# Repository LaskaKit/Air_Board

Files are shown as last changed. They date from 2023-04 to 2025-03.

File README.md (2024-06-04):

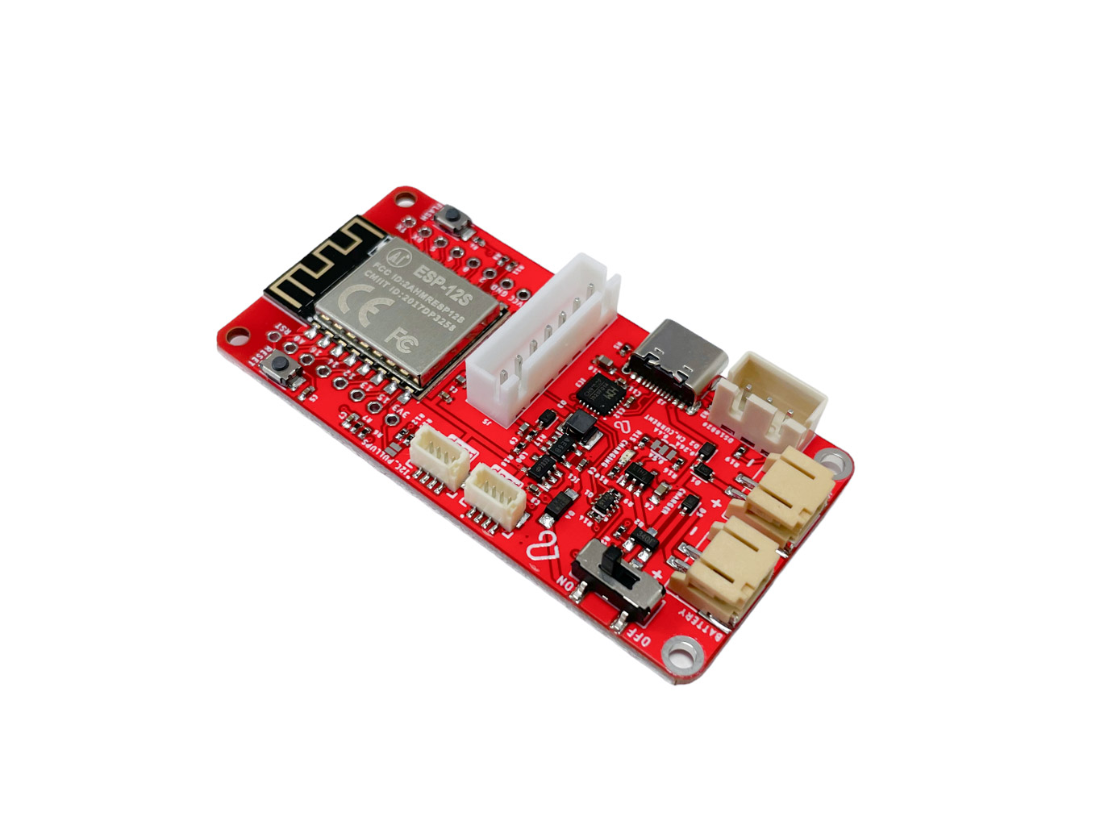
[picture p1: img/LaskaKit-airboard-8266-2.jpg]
Airboard - TOP


# LaskaKit AirBoard ESP8266 

The quality of the air we breathe is very important but unfortunately neglected. Thanks to a close cooperation with [sensorvzduchu.cz](https://www.senzorvzduchu.cz/) we have developed a board fully compatible with https://sensor.community/. This is one of the largest services for storing and visualizing data from home and semi-professional metestanice. 

Of course, it is not necessary to use Airboard only with sensor.community. You can use it with another popular service [TMEP.eu](https://tmep.eu/). Or you can send the data to your own server, where you can run HomeAssistant or Grafana. 

We have fully respected the demands and requirements of the sensor.community during development so that the LaskaKit AirBoard is fully compatible. No obstacles, just improvements over the normal NodeMCU wiring. </br>
And the result? The basis is a fully supported module with ESP8266. To this you can easily connect I2C sensors (SDA - GPIO0, SCL - GPIO2) via two [uSup connectors(what is it?)](https://blog.laskakit.cz/predstavujeme-univerzalni-konektor-pro-propojeni-modulu-a-cidel-%ce%bcsup/). With this connector compatible with SparkFun Qwiic and Adafruit STEMMA, you can connect dozens of different I2C sensors. </br>
Which on? For example [BME688 - Pressure, Temperature, Humidity and Air Quality Sensor](https://www.laskakit.cz/laskakit-bme688-senzor-tlaku--teploty--vlhkosti-a-kvalitu-vzduchu/), [SGP41 - VOC and Nox Air Quality Sensor](https://www.laskakit.cz/laskakit-sgp41-voc-a-nox-senzor-kvality-ovzdusi/) and you can display all that data on the [1.3" OLED display](https://www.laskakit.cz/laskakit-oled-displej-128x64-1-3--i2c/?variantId=11903), [SCD41 for measurement of CO2, temperature and humidity](https://www.laskakit.cz/laskakit-scd41-senzor-co2--teploty-a-vlhkosti-vzduchu/), sensor SHT41 [temperature and humidity](https://www.laskakit.cz/laskakit-sht40-senzor-teploty-a-vlhkosti-vzduchu/) and [sensor of pressure, temperature, humidity BME280](https://www.laskakit.cz/arduino-senzor-tlaku--teploty-a-vlhkosti-bme280/), [RTC - Real Time Clock](https://www.laskakit.cz/laskakit-ds3231-orig--rtc-hodiny-realneho-casu/) with DS323.

The UART is connected to RX (GPIO5), TX (GPIO4) pins, the ADC input from the voltage divider connected to the battery is connected to the single ADC input of the ESP8266.
And that's certainly not all.

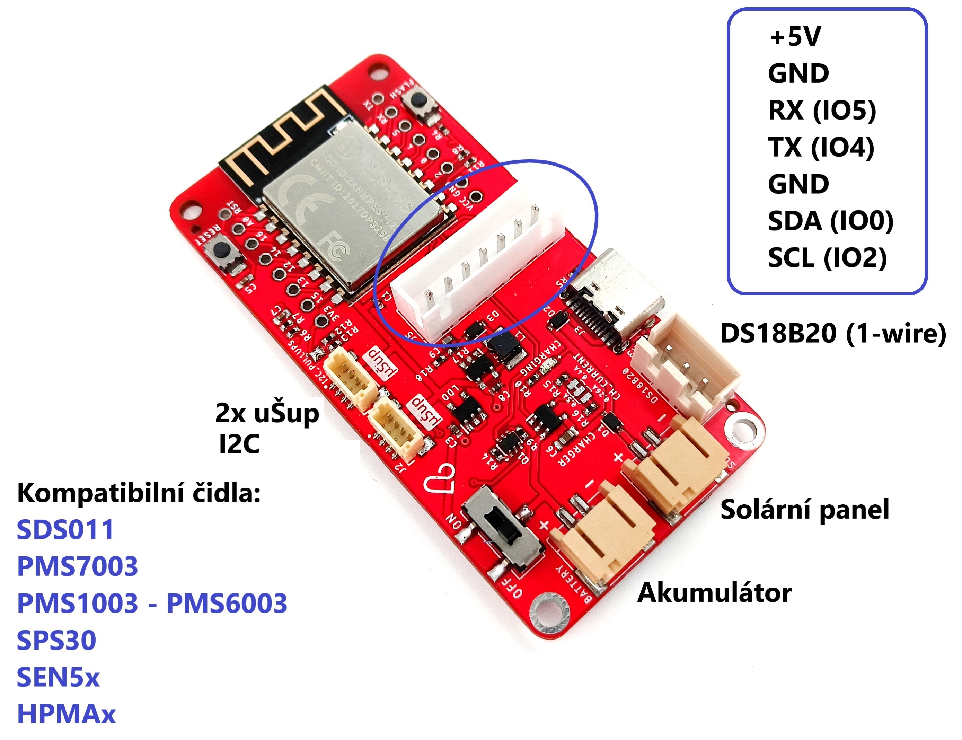
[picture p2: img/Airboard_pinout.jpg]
Airboard - pinout


You can also connect particulate sensors to the AirBoard very easily - there is a 7-pin connector on the board with I2C interface and UART interface and of course power supply. </br>
How and what to connect where we wrote in https://github.com/LaskaKit/Air_Board/blob/main/input/sensors.xlsx</br>
Some sensors need a 5V power supply, usually because of the fan or laser. We also kept this in mind during the design - we added a step-up converter to the board. With this you can power sensors that also need 5V power.

Fro version 1.2, it is now possible to choose whether the 5V output voltage for the connected sensors will be permanently on, or whether it can be switched on/off as needed using GPIO pin IO12.

If you're asking if you can connect a 5V powered sensor to the ESP8266, overwhelmingly yes. The sensors are indeed 5V powered, but the output is 3.3V compatible (but always confirm this in the sensor datasheet).

And what else can you find on the board? Three-pin connector for high-quality connection of temperature sensor DS18B20 (1-wire bus, contains 4k7 pull-up), connector for solar panel (we recommend 6V) and connector for connecting the accumulator.

You don't need a programmer. It is built-in on the board itself. Just plug in the USB-C cable to your laptop and upload your code. 

## This board is available on https://www.laskakit.cz/laskakit-airboard-8266-deska-pro-mereni-kvality-vzduchu/

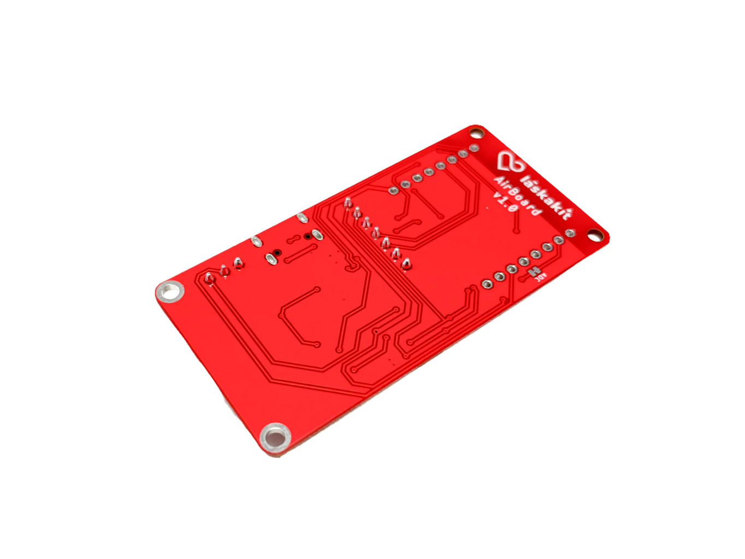
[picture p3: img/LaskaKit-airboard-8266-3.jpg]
Airboard - TOP


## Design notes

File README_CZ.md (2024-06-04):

Airboard - TOP

# LaskaKit AirBoard ESP8266 
Kvalita vzduchu, který dýcháme, je velmi důležitá ale bohužel opomíjená. Díky úzké spolupráci se [senzorvzduchu.cz](https://www.senzorvzduchu.cz/) jsme společně vyvinuli desku plně kompatibilní se https://sensor.community/cz/. To je jedna z největších služeb pro ukládání a vizualizaci dat z domácích a poloprofesionálních metestanice. 

Airboard samozřejmě nemusíš použít jenom se sensor.community. Můžeš jej využít s další populární službou [TMEP.cz](https://tmep.cz/). Nebo si můžeš posílat data na svůj server, kde ti třeba běží HomeAssistant nebo Grafana. 

Plně jsme při vývoji respektovali nároky a požadavky sensor.community tak, aby deska LaskaKit AirBoard byla plně kompatibilní. Žádné překážky, jenom vylepšení oproti běžnému zapojení s NodeMCU. </br>
A výsledek? Základem je plně podporovaný modul s ESP8266. K tomu lze snadno připojit I2C čidla (SDA - GPIO0, SCL - GPIO2) přes dva [uŠup konektory(co to je?)](https://blog.laskakit.cz/predstavujeme-univerzalni-konektor-pro-propojeni-modulu-a-cidel-%ce%bcsup/). Díky tomuto konektoru kompatibilním se SparkFun Qwiic a Adafruit STEMMA, můžeš připojit desítky nejrůznějších I2C čidel. 
UART je připojen na piny RX (GPIO5), TX (GPIO4), ADC vstup z děliče napětí připojeného na akumulátor je připojen na jediný ADC vstup ESP8266.
A to rozhodně není všechno.

Airboard - pinout

K AirBoard můžeš velmi jednoduše připojit i čidla pevných částic - na desce je 7pinový konektor s I2C rozhraním i UART rozhraním a samozřejmě napájením. Díky tomuto konektoru můžeš připojit nejméně 6 typů senzorů pevných částic. Některé moduly navíc obsahují i čidlo teploty a vlhkosti, například SEN5x.</br>
Jak a co kam připojit jsme sepsali v https://github.com/LaskaKit/Air_Board/blob/main/input/sensors.xlsx</br>
Některá čidla potřebují 5V napájení, většinou kvůli ventilátoru nebo laseru. I na toto jsme při návrhu mysleli - na desku jsme přidali step-up (zvyšující) měnič na 5V. Tím můžeš napájet čidla, která potřebují i 5V napájení.

Od verze 1.2 je nově možnost zvolit zda bude výstupní napětí 5V pro připojená čidla trvale zapnuté, nebo ho lze podle potřeby zapínat/vypínat pomocí GPIO pinu IO12.

Pokud se ptáš, jestli můžeš 5V napájené čidlo připojit k ESP8266, tak v drtivé většině ano. Čidla jsou totiž sice napájená 5V, ale výstup je 3.3V kompatibilní (tohle si ale raději vždy potvrď v katalogovém listu čidla).

A co na desce ještě najdeš? Třípinový konektor pro kvalitní připojení čidla teploty DS18B20 (1-wire sběrnice, obsahuje 4k7 pull-up), konektor pro solární panel (ten doporučujeme 6V) a konektor pro připojení akumulátoru. </br>
Ten je napájený z čipu TP4054 a na desce najdeš pájecí most, kterým si zvolíš nabíjecí proud - 260mA nebo 400mA.

K programování budeš nepotřebuješ programátor. Ten už je na desce a stačí tak jenom zapojit USB-C kabel do tvého počítače a nahrát program. 

## Tuto desku si můžeš objednat na https://www.laskakit.cz/laskakit-airboard-8266-deska-pro-mereni-kvality-vzduchu/

Airboard - TOP

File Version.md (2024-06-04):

### Version 1.2
- Přepojení ADC děliče přímo na VBAT
- Přidána propojka ADC dělič <-> VBAT - ADC_BATT
- Přidána možnost spínání pro 5V měnič - IO12
- Změna rezistoru pro LED na 2k
#### Version 1.1
- Added CH9102
#### Version 1.0
- Opraven dělič napětí - 1M/294k
- Změna napájení 5V měniče - napájen přímo z vypínače, ne z 3,3V větve
#### Version 0.0
- Vývojová

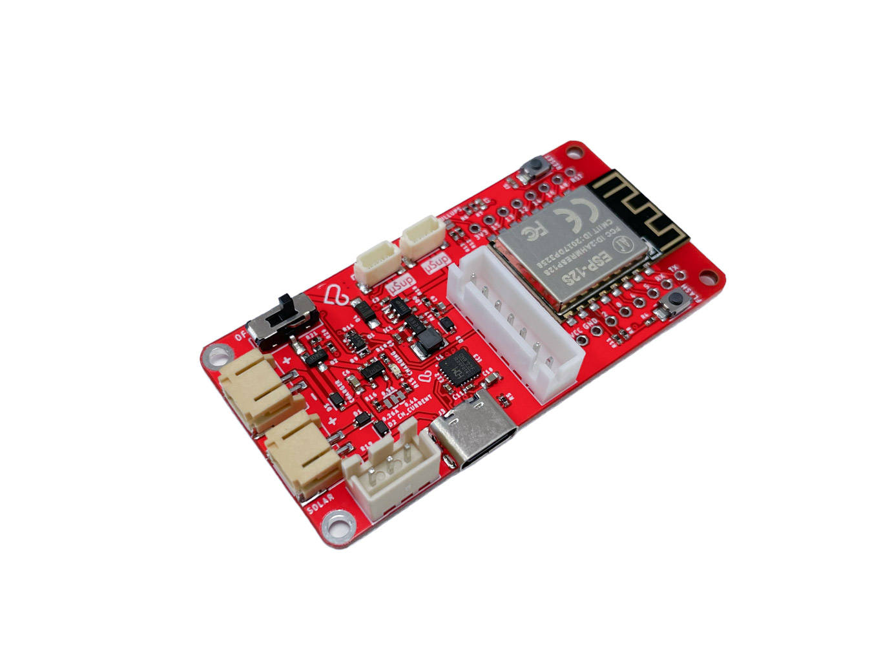
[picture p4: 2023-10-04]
img/LaskaKit-airboard-8266-1.jpg

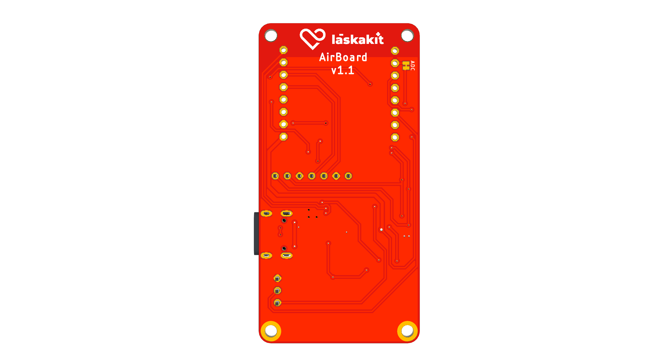
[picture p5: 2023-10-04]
img/LaskaKit_AirBoard_back.png

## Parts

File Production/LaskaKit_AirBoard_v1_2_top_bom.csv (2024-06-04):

Comment | Designator | Footprint | LCSC Part #
1M | R6 R23 | R0402
1N4007W | D4 | SOD123-F
1N5819WS | D3 | SOD323-R
1k65 | R15 | R0402
1uF | C6 | C0603
750 | R10 | R0402
3k3 | R16 | R0402
4.7k | R19 | R0402
5.1k | R18 | R0402
5k1 | R3 R5 | R0402
10k | R1 R2 R4 R8 R9 R11 R12 R13 R14 R20 R22 | R0402
10uH | L1 | L1210 | C86069
15.4k | R17 | R0402
22uF | C2 C3 C4 C8 C9 | C0402
22uF | C10 | C0603
22uF | C13 | C0402
100k | R21 | R0402
100n | C11 C12 | C0402
100nF | C1 C5 C7 | C0402
294k | R7 | R0402
AO3401 | Q2 | SOT23
AP2191WG-7 | IC2 | SOT25 | C141321
AP3012 | IC1 | SOT95P280X135-5N | C460356
BAT60B | D1 D2 D5 | SOD323-R
CH9102F | IC3 | QFN24-4X4
ESP-12 | U1 | ESP12-SMD
HT7833 | LDO | SOT23-5
JST-PH-2/90SMD | BATTERY SOLAR | S2B-PH-SM4 | C47647
JST-SH 4P | J1 J2 | 1X04_1MM_RA_VERT | C371588
MMDT3904 | Q1 | SC70-6 | C268586
RED | CHARGING | CHIP-LED0603 | C241893
TA-3531-A2 | SW1 | TA-3530A-A2 | C514025
TP4054 | CHARGER | SOT-23-5
TS-1088R-02026 | FLASH RESET | TS1088R02026
USB-C_2-16PIN | J3 | USBC_USB-C-16P-5 | C2837092
JST-XH_7P | J5 | JST-XH_7P | C144398
JST-XH_3P | DS18B20 | JST-XH_3P

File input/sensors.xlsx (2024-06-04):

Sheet: Sheet1
 | AirBoard pins and colors | LA131056 SDS011 4.7-5.3V 70mA±10mA
connector | JST-XH-7 | JST-XH-7
1 | 5V | Pin 1 (TX @3.3V) -> (RX) Pin D1 (GPIO5)
2 | GND | Pin 2 (RX@3.3V) -> (TX) Pin D2 (GPIO4)
3 | (RX) Pin D1 (GPIO5) | Pin 3 (GND) -> GND
4 | (TX) Pin D2 (GPIO4) | ~~Pin 4 (2.5m) -> unused~~
5 | GND (SEL) | Pin 5 (5V) -> VU
6 | SDA Pin D3 (GPIO0) | ~~Pin 6 (1m) -> unused~~
7 | SCL Pin D4 (GPIO2) | ~~Pin 7 (NC) -> unused~~
 | AirBoard pins and colors | Honeywell PM sensor 5 V ±0.2 V 80mA max.
connector | JST-XH-7
1 | 5V | ~~Pin 1 (3.3V 100 mA out) -> unused~~
2 | GND | Pin 2 (5V) -> VU
3 | (RX) Pin D1 (GPIO5) | ~~Pin 3 (NC) -> unused~~
4 | (TX) Pin D2 (GPIO4) | ~~Pin 4 (NC) -> unused~~
5 | GND (SEL) | ~~Pin 5 TEST reserved for future use) -> unused~~
6 | SDA Pin D3 (GPIO0) | Pin 6 (TX @3.3V) -> Pin D1 (GPIO5)
7 | SCL Pin D4 (GPIO2) | Pin 7 (RX @3.3V) -> Pin D2 (GPIO4)
 |  | Pin 8 (GND) -> GND
 | AirBoard pins and colors | PMS7003 4.5-5.5V 100mA max.
connector | JST-XH-7
1 | 5V | Pin 1 (5V VCC) -> VU
2 | GND | Pin 2 (5V VCC) -> VU
3 | (RX) Pin D1 (GPIO5) | Pin 3 (GND) -> GND
4 | (TX) Pin D2 (GPIO4) | Pin 4 (GND) -> GND
5 | GND (SEL) | ~~Pin 5 (RESET) -> unused~~
6 | SDA Pin D3 (GPIO0) | ~~Pin 6 (NC) -> unused~~
7 | SCL Pin D4 (GPIO2) | Pin 7 (RX @3.3V) -> Pin D2 (GPIO4)
 |  | ~~Pin 8 (NC) -> unused~~
 |  | Pin 9 (TX @3.3V) -> Pin D1 (GPIO5)
 |  | ~~Pin 10 (SET ) -> unused~~
 | AirBoard pins and colors | PMS1003 to PMS6003 4.5-5.5V
connector | JST-XH-7
1 | 5V | Pin 1 (5V VCC) -> VU
2 | GND | Pin 2 (GND) -> GND
3 | (RX) Pin D1 (GPIO5) | ~~Pin 3 (SET) -> unused~~
4 | (TX) Pin D2 (GPIO4) | Pin 4 (RX @3.3V) -> Pin D2 (GPIO4)
5 | GND (SEL) | Pin 5 (TX @3.3V) -> Pin D1 (GPIO5)
6 | SDA Pin D3 (GPIO0) | ~~Pin 6 (RESET) -> unused~~
7 | SCL Pin D4 (GPIO2) | ~~Pin 7 (NC) -> unused~~
 |  | ~~Pin 8 (NC) -> unused~~
 | AirBoard pins and colors | LA131057 SPS30 (I2C, 4.5 - 5.5V) 80mA max.
connector | JST-XH-7 | JST-ZHR-5
1 | 5V | Pin 1 (5V) -> Pin VU/VIN
2 | GND | Pin 2 (SDA @3.3V) -> Pin D3 (GPIO0)
3 | (RX) Pin D1 (GPIO5) | Pin 3 (SCL @3.3V) -> Pin D4 (GPIO2)
4 | (TX) Pin D2 (GPIO4) | Pin 4 (SEL) -> Pin GND
5 | GND (SEL) | Pin 5 (GND) -> Pin GND
6 | SDA Pin D3 (GPIO0)
7 | SCL Pin D4 (GPIO2)
 | AirBoard pins and colors | LA131058 a LA131059 SEN5x (I2C, 4.5 - 5.5V) 100mA max.
connector | JST-XH-7 | JST-GHT-06V-S
1 | 5V | Pin 1 (5V) -> Pin VU/VIN
2 | GND | Pin 2 (GND) -> Pin GND
3 | (RX) Pin D1 (GPIO5) | Pin 3 (SDA @3.3V) -> Pin D3 (GPIO0)
4 | (TX) Pin D2 (GPIO4) | Pin 4 (SCL @3.3V) -> Pin D4 (GPIO2)
5 | GND (SEL) | Pin 5 (SEL) -> Pin GND
6 | SDA Pin D3 (GPIO0) | ~~Pin 6 (NC) -> unused~~
7 | SCL Pin D4 (GPIO2)

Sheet: SDS011
datasheet (https://www.laskakit.cz/user/related_files/sds011_laser_pm2-5-v1-3.pdf) |  | 5V 70mA±10mA
No | Name | Comment
1 | NC | Not Connect
2 | 1μm | PM2.5: 0-999μg/m3;PWM Output
3 | 5V | 5V Input
4 | 2.5μm | PM10: 0-999 μg/m3;PWM Output
5 | GND | Ground
6 | R | RX of UART(TTL)@3.3V
7 | T | TX of UART(TTL)@3.3V

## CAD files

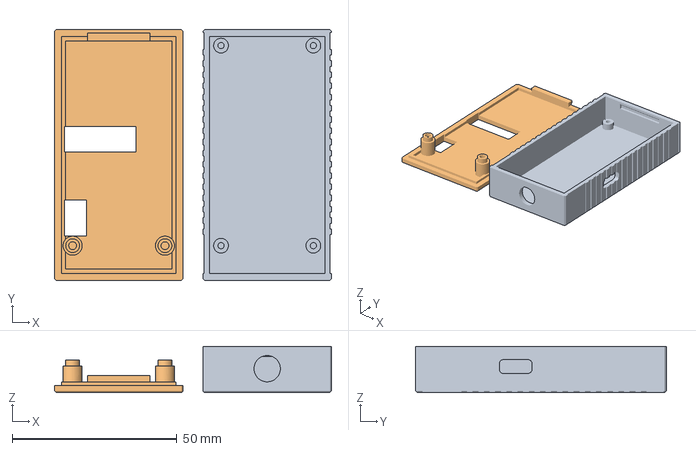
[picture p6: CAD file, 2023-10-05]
3D/airboard_case.3mf
84.0 x 76.0 x 14.0 mm
Top_cover v10.stl
Bottom_cover_general v35.stl

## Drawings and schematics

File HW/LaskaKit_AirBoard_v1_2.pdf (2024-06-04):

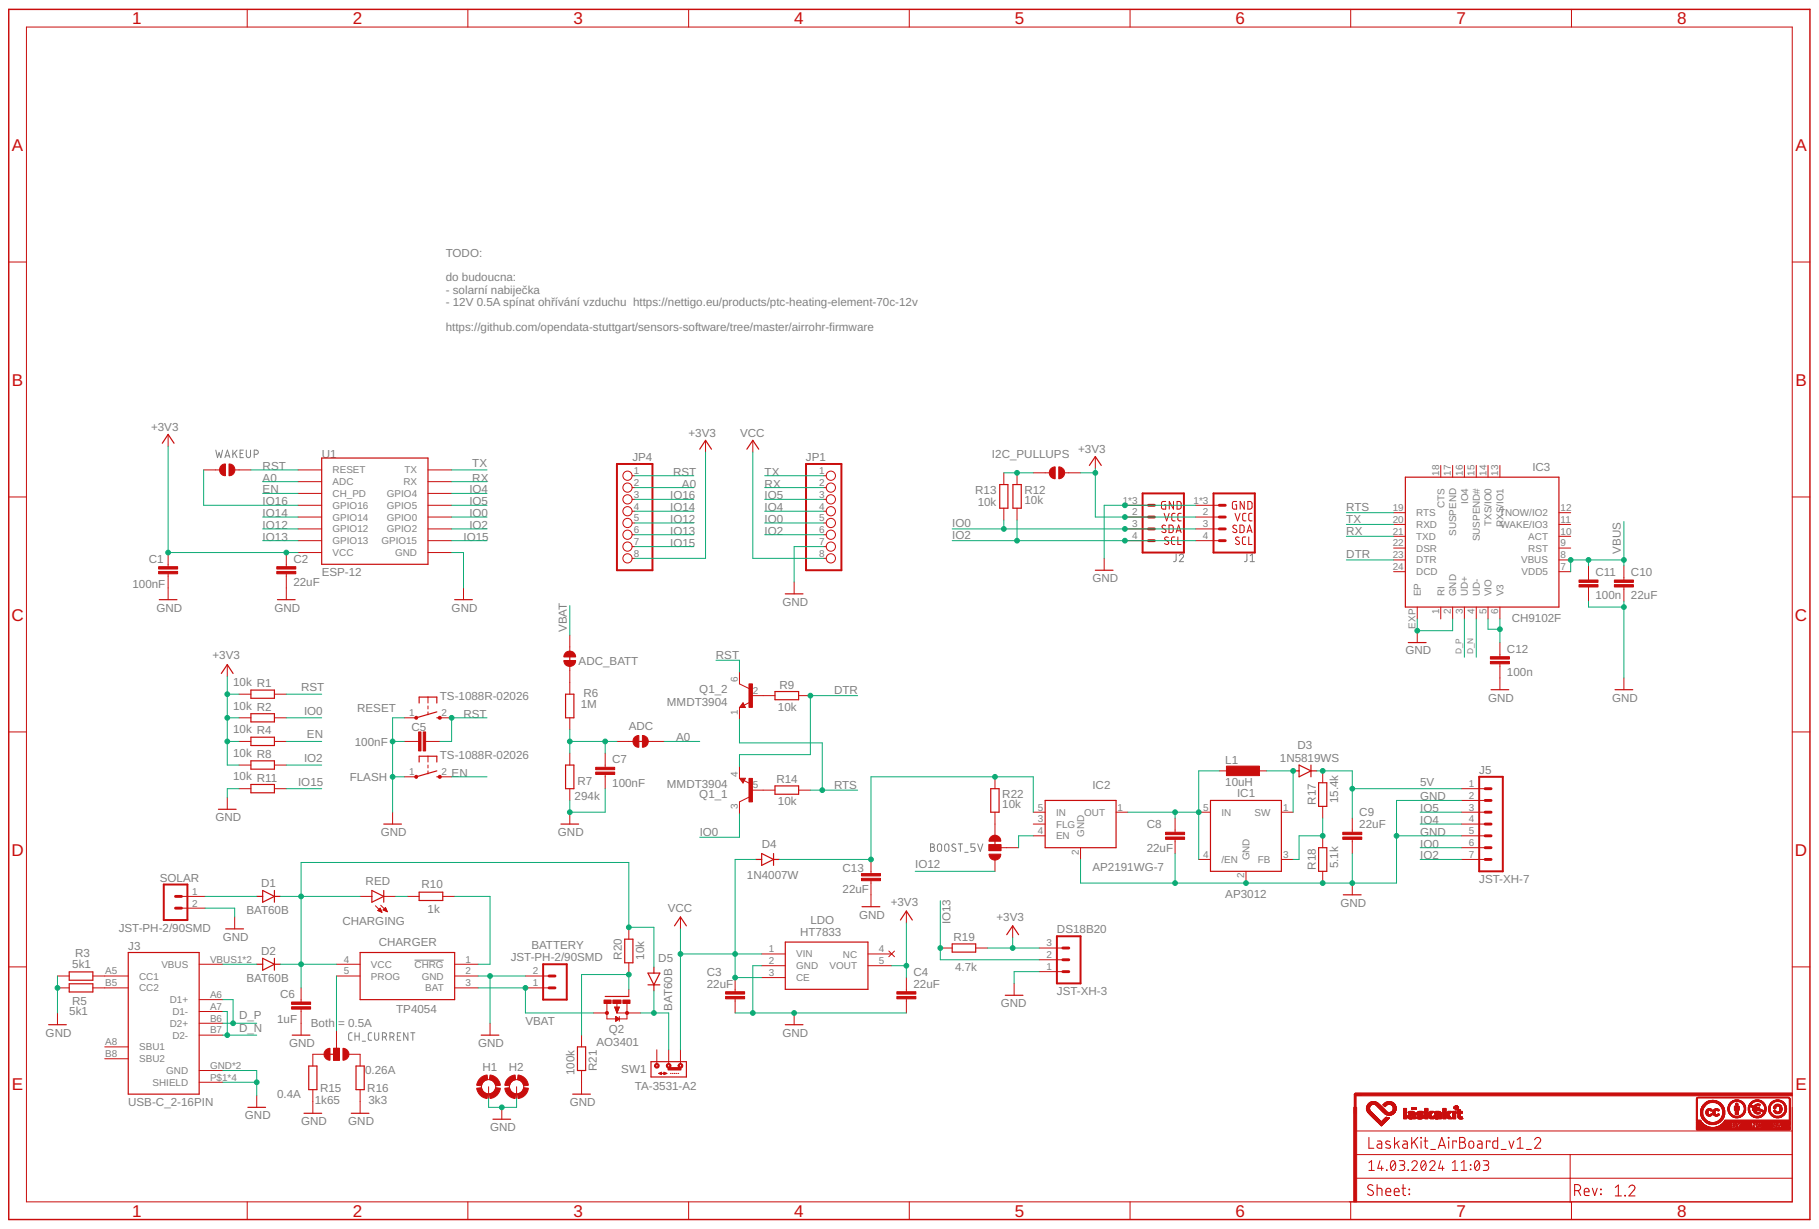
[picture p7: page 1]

TODO: do budoucna: - solarní nabiječka

- 12V 0.5A spínat ohřívání vzduchu https://nettigo.eu/products/ptc-heating-element-70c-12v https://github.com/opendata-stuttgart/sensors-software/tree/master/airrohr-firmware

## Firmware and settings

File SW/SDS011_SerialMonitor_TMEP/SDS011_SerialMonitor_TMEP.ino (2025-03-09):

/*
* Example code for AirBoard and SDS011
* The measuread values (PM10) are send to 
* Serial Monitor and to TMEP.cz or TMEP.eu
* This example creates SoftwareSerial where is SDS011 connected
* IO5 - RX connect to TX of SDS011
* IO4 - TX connect to RX of SDS011
*
* Libraries:
* Library for SoftwareSerial
* https://github.com/plerup/espsoftwareserial
* Library for SDS011
* https://github.com/lewapek/sds-dust-sensors-arduino-library/
*
* Hardware:
* SDS011 - https://www.laskakit.cz/nova-pm-sds011-opticky-senzor-kvality-ovzdusi-pm2-5-pm10/
* Air board - https://www.laskakit.cz/laskakit-airboard-8266-deska-pro-mereni-kvality-vzduchu/
* Cable for SDS011 and Air board - https://www.laskakit.cz/laskakit-airboard-propojovaci-kabel-pro-nova-pm-sds011-opticky-senzor-kvality-ovzdusi/
*
* laskakit 2024
*/

#include <ESP8266WiFi.h>
#include <SoftwareSerial.h>
#include "SdsDustSensor.h"

SoftwareSerial SDS_Serial(5, 4); // RX | TX
SdsDustSensor sds(SDS_Serial);

unsigned int waitTime = 60000; // in ms

/* -------------- Wi-Fi --------------- */
const char* ssid     = "SSID";
const char* password = "PASSWORD";
const char* host = "HOSTNAME.tmep.cz"; // or HOSTNAME.tmep.eu

void setup() 
{
  Serial.begin(115200); // Serial for output to the Arduino Serial Monitor
  
  /* -------------- SDS011 --------------- */
  sds.begin();  // SDS011 Serial begin (replaced by SoftwareSerial)
  /* -------------- END SDS011 ---------------- */

  /* -------------- Wi-Fi --------------- */
  WiFi.begin(ssid, password);
  unsigned int numberOfConnections= 0;
  while (WiFi.status() != WL_CONNECTED) {
    delay(500);
    Serial.print(".");
    numberOfConnections++;

    Serial.println("Number Of Connections:");
    Serial.println(numberOfConnections);

    // if ESP8266 can't connect to WiFi -> go to deep.sleep
    if (numberOfConnections > 10)
    {
        //if you want to use deep sleep, connect RST with GPIO16 (16) on header
        //ESP.deepSleep(waitTime/1000 * 1000000, WAKE_RF_DEFAULT);
        delay(waitTime);
        return;
    }
  }
  /* -------------- END Wi-Fi ---------------- */

}

void loop() 
{
  /* -------------- SDS011 --------------- */
  PmResult pm = sds.queryPm();  // read the values
  if (pm.isOk()) // check if the measurement is valid and print to Serial Monitor
  {
    Serial.print("PM2.5 = ");
    Serial.print(pm.pm25);
    Serial.print(", PM10 = ");
    Serial.println(pm.pm10);

    /* -------------- Wi-Fi --------------- */
    WiFiClient client;
    const int httpPort = 80;
    if (!client.connect(host, httpPort)) 
    {
      Serial.println("connection failed");
      return;
    }
  
    // We now create a URI for the request
    String url = "/index.php?";
  
    Serial.print("Requesting URL: ");
    Serial.println(url);
  
    // This will send the request to the server, the GUID is "pm"
    client.print(String("GET ") + url + "pm=" + String(pm.pm10) + " HTTP/1.1\r\n" +
              "Host: " + host + "\r\n" + 
              "Connection: close\r\n\r\n");
  
    delay(10);
  
    while(client.available())
    {
      String line = client.readStringUntil('\r');
      Serial.print(line);
    }
    /* -------------- END Wi-Fi ---------------- */
    
  } 
  else 
  {
    Serial.print("Could not read values from sensor, reason: ");
    Serial.println(pm.statusToString());
  }
  /* -------------- END SDS011 ---------------- */
  
  //if you want to use deep sleep, connect RST with GPIO16 (16) on header
  //ESP.deepSleep(waitTime/10000 * 1000000, WAKE_RF_DEFAULT);
  delay(waitTime);

}

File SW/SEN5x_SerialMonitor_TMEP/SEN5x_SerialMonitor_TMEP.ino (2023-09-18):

/*
* Example code for AirBoard and SEN5x
* The measuread values are send to 
* Serial Monitor and to TMEP.cz (TMEP.eu)
* If you want to use deep sleep function, short RST with GPIO16 (16) on header of AirBoard.
*
* Libraries:
* https://github.com/Sensirion/arduino-i2c-sen5x
*
* laskakit 2023
*/

#include <ESP8266WiFi.h>
#include <SensirionI2CSen5x.h>
#include <Wire.h>

unsigned int waitTime = 60000; // in ms

/* -------------- SEN5x --------------- */
SensirionI2CSen5x sen5x;

uint16_t error;
char errorMessage[256];

/* -------------- Wi-Fi --------------- */
const char* ssid     = "SSID";
const char* password = "PASSWORD";
const char* host = "HOSTNAME.tmep.cz"; // or HOSTNAME.tmep.eu


void setup() 
{
  Serial.begin(115200);
  Wire.begin(0, 2);

  /* -------------- SEN5x --------------- */
  sen5x.begin(Wire);
  float tempOffset = 0.0;
  error = sen5x.setTemperatureOffsetSimple(tempOffset);
  if (error)
  {
    Serial.print("Error trying to execute setTemperatureOffsetSimple(): ");
    errorToString(error, errorMessage, 256);
    Serial.println(errorMessage);
  } 
  else 
  {
    Serial.print("Temperature Offset set to ");
    Serial.print(tempOffset);
    Serial.println(" deg. Celsius (SEN54/SEN55 only)");
  }

  // Start Measurement
  error = sen5x.startMeasurement();
  if (error) 
  {
    Serial.print("Error trying to execute startMeasurement(): ");
    errorToString(error, errorMessage, 256);
    Serial.println(errorMessage);
  }
  /* -------------- END SEN5x ---------------- */

  /* -------------- Wi-Fi --------------- */
  WiFi.begin(ssid, password);
  unsigned int numberOfConnections= 0;
  while (WiFi.status() != WL_CONNECTED) {
    delay(500);
    Serial.print(".");
    numberOfConnections++;

    Serial.println("Number Of Connections:");
    Serial.println(numberOfConnections);

    // if ESP8266 can't connect to WiFi -> go to deep.sleep
    if (numberOfConnections > 10)
    {
        //if you want to use deep sleep, connect RST with GPIO16 (16) on header
        //ESP.deepSleep(waitTime/1000 * 1000000, WAKE_RF_DEFAULT);
        delay(waitTime);
        return;
    }
  }
  /* -------------- END Wi-Fi ---------------- */
}

void loop() 
{
  /* -------------- SEN5x --------------- */
  // Read Measurement
  float massConcentrationPm1p0;
  float massConcentrationPm2p5;
  float massConcentrationPm4p0;
  float massConcentrationPm10p0;
  float ambientHumidity;
  float ambientTemperature;
  float vocIndex;
  float noxIndex;

  error = sen5x.readMeasuredValues(
        massConcentrationPm1p0, massConcentrationPm2p5, massConcentrationPm4p0,
        massConcentrationPm10p0, ambientHumidity, ambientTemperature, vocIndex,
        noxIndex);

  if (error) 
  {
    Serial.print("Error trying to execute readMeasuredValues(): ");
    errorToString(error, errorMessage, 256);
    Serial.println(errorMessage);
  } 
  
  else 
  {
    Serial.print("MassConcentrationPm1p0:");
    Serial.print(massConcentrationPm1p0);
    Serial.print("\t");
    Serial.print("MassConcentrationPm2p5:");
    Serial.print(massConcentrationPm2p5);
    Serial.print("\t");
    Serial.print("MassConcentrationPm4p0:");
    Serial.print(massConcentrationPm4p0);
    Serial.print("\t");
    Serial.print("MassConcentrationPm10p0:");
    Serial.print(massConcentrationPm10p0);
    Serial.print("\t");
    Serial.print("AmbientHumidity:");
    if (isnan(ambientHumidity)) 
    {
      Serial.print("n/a");
    } 
    else 
    {
      Serial.print(ambientHumidity);
    }
    Serial.print("\t");
    Serial.print("AmbientTemperature:");
    if (isnan(ambientTemperature)) 
    {
      Serial.print("n/a");
    } 
    else 
    {
      Serial.print(ambientTemperature);
    }
    Serial.print("\t");
    Serial.print("VocIndex:");
    if (isnan(vocIndex)) 
    {
      Serial.print("n/a");
    } 
    else 
    {
      Serial.print(vocIndex);
    }
    Serial.print("\t");
    Serial.print("NoxIndex:");
    if (isnan(noxIndex)) 
    {
      Serial.println("n/a");
    } 
    else 
    {
      Serial.println(noxIndex);
    }
  }
  /* -------------- END SEN5x ---------------- */

  /* -------------- Wi-Fi --------------- */
  WiFiClient client;
  const int httpPort = 80;
  if (!client.connect(host, httpPort)) 
  {
    Serial.println("connection failed");
    return;
  }

  // We now create a URI for the request
  String url = "/index.php?";

  Serial.print("Requesting URL: ");
  Serial.println(url);

  // This will send the request to the server, the GUID is "pm"
  client.print(String("GET ") + url + "pm=" + String(massConcentrationPm2p5) + " HTTP/1.1\r\n" +
            "Host: " + host + "\r\n" + 
            "Connection: close\r\n\r\n");

  delay(10);

  while(client.available())
  {
    String line = client.readStringUntil('\r');
    Serial.print(line);
  }
  /* -------------- END Wi-Fi ---------------- */
  //if you want to use deep sleep, connect RST with GPIO16 (16) on header
  //ESP.deepSleep(waitTime/10000 * 1000000, WAKE_RF_DEFAULT);
  delay(waitTime);
}

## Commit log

2023-08-16 new ver, added ch9102
    [LaskaKit_AirBoard_top_bom.csv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]
2024-06-04 new version
    [LaskaKit_AirBoard_top_bom_v_1_1.csv, LaskaKit_AirBoard_v1_2_top_bom.csv, sensors.xlsx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]
